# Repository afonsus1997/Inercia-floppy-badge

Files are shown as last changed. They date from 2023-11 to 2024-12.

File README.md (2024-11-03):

# Inércia 2024 Floppy Badge

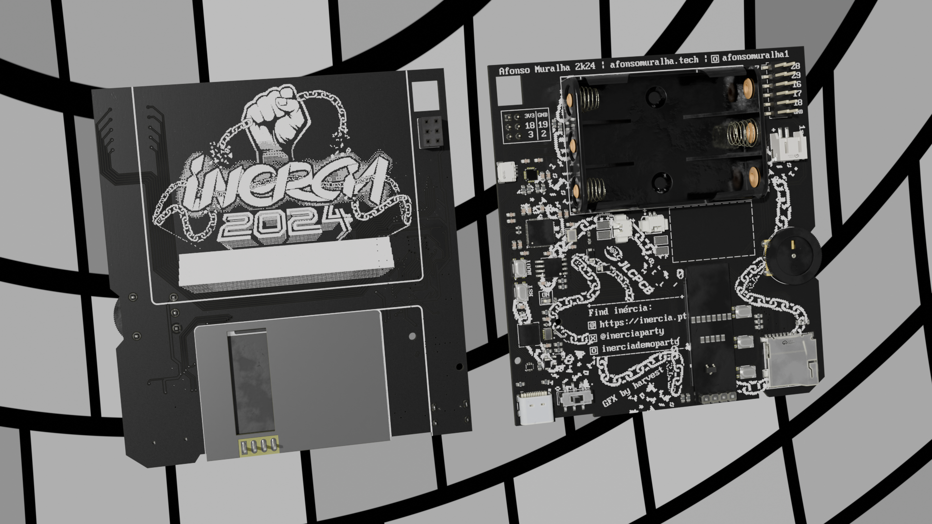
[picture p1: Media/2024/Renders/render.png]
Render


## Introduction

Missed last year’s Inércia 2023 badge? This year, they’re back and even better! Inércia 2024 badges now come with a mini OLED screen—perfect for displaying custom text, animations, and more, alongside the ability to play your favorite .mod tunes. 

## Sponsors

JLCPCB LOGO

JLCPCB helped make this project possible! All the manufacturing and assembly of the prototypes and the final badges were made using JLCPCB services.

[Check out JLCPCB here!](https://jlcpcb.com/)

## Specifications and Features

- **Processor:** RP2040
- **Memory:** 264kB on-chip SRAM, 32Mb external flash
- **Power Supply:** USB or 3xAAA
- **Connectivity:** USB, external GPIO, SAO
- **Dimensions:** Very close to a real floppy!
## Design Files and Schematics

All design files, including schematics, PCB layouts, and 3D models, are available for download:

- [Kicad Project folder](Hardware/2024/mod-badge-inercia)
- [Schematic PDF](Hardware/2024/mod-badge-inercia/mod-badge-inercia.pdf)
- [3D Models (STEP)](Hardware/2024/mod-badge-inercia/mod-badge-inercia.step)

## Pictures and Renders

Below are some pictures and renders of the project to give you a closer look:

- Top View
- Side View
- 3D Render

## Changelog

### Credits

- oled footprint from: https://github.com/gorbachev/KiCad-SSD1306-0.91-OLED-4pin-128x32.pretty
- oled 3d model from Stilet Fox (https://grabcad.com/library/oled-0-91-128x32-1)
- battery holder 3d model from Tomasz (https://grabcad.com/library/3-x-aaa-battery-holder)
- potentiometer model from NGOUBO OLIVIER (https://grabcad.com/library/potentiometer-52)
- push button model from Shawn Melanson (https://grabcad.com/library/skrpace010-push-button-switch-1)
- picoblade model from Владимир «AVRASM1234» Иванишин (https://grabcad.com/library/molex-picoblade-connectors-1-25-mm-right-angle-1)

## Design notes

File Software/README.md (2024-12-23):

# Software Guide

This README provides instructions on setting up the development environment, programming, and debugging the **Inercia Floppy Badge**.

------

## Projects:

- [inercia_badge_sw_pio](https://github.com/afonsus1997/Inercia-floppy-badge/tree/main/Software/inercia_badge_sw_pio) is the main production firmware
- [inercia_badge_sw_tinygl](https://github.com/afonsus1997/Inercia-floppy-badge/tree/main/Software/inercia_badge_sw_tinygl) is the beta version with ported tinyGL lib

## Updating Your Badge

1. Download the latest .uf2 firmware file from the [releases page](https://github.com/afonsus1997/Inercia-floppy-badge/releases).
2. Connect the badge to your PC.
3. With your badge turned off hold the boot button and with the boot button still pressed, turn on the badge. A mass storage device should appear.
4. Copy the .uf2 firmware file to the badge mass storage device.
5. The badge is now updated and should reboot automatically! 

## Development Environment

The development environment is built around [PlatformIO](https://platformio.org), which allows for efficient dependency management and provides greater control over the build process compared to the Arduino IDE. Is it perfect? No. But PlatformIO offers (what seems to us) the best balance of usability, distribution ease, and customization. If you have suggestions for improvement, we’re always open to feedback!

### Setting Up PlatformIO

To get started, install PlatformIO following the official [installation guide](https://platformio.org/install/). You can use:

- **PlatformIO VS Code Extension** for a graphical interface.

- **PlatformIO CLI** for command-line workflows.

> ##### Note: Additional steps when using Windows
> Windows has a default limitation on file path lengths (260 characters), which **WILL** cause issues when working with the PlatformIO project. To avoid errors:
>
> - Enable long file path support in Windows:
>
>   - Open the **Local Group Policy Editor** (`gpedit.msc`).
>
>   - Navigate to `Computer Configuration > Administrative Templates > System > Filesystem`.
>
>   - Enable the policy **Enable Win32 long paths**.
>
>   - Reboot

------

## Accessing the Codebase

The main firmware is located in the [`Software/inercia_badge_sw_pio`](https://github.com/afonsus1997/Inercia-floppy-badge/tree/main/Software/inercia_badge_sw_pio) directory of the repository. This is the most up-to-date source code for the badge.

To begin:

1. Open the project in PlatformIO.
2. Allow PlatformIO to scan the project files.

------

## Build Environments

Once the project is loaded, you’ll find two build environments in the `platformio.ini` file:

1. **`env:pico_usb`**
   - Use this for flashing the badge firmware via USB.
2. **`env:pico_cmsis`**
   - Select this if you are using a debug probe. [More info here](#).

> ##### Note: (more) Additional steps when using Windows
> For the first **USB** firmware upload, you need to plug in the badge with the BOOTL button pressed so that it shows up as UF2 drive.
> Then, use Zadig to change the driver of the RP2040 to WinUSB.

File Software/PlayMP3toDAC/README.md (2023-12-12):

# Inércia 2023 Floppy Badge MP3 Support

This little *CircuitPython* script allows for the playback of .mp3 (and .wav if you really want to) from local storage and micro SD card.

## Usage

Flash CircuitPython 8.x from [here](https://circuitpython.org/board/raspberry_pi_pico/) onto the badge.

After the reboot copy the `lib` directory and `code.py` to the root of the, now available, `CIRCUITPY` device/directory on your computer.

The mixer in the firmware expects a single channel with a sample rate of 22050 Hz, so there is a `resampler.py` script that expects mp3 files in a mp3 folder and resamples everything to the required format. There's also a `requirements.txt` file. I recommend you use `venv` or something of the sorts.

Place your mp3 files into an `mp3` directory on you micro SD card.

That's pretty much it. Power the badge and it should play sound.

## Dependencies

- CircuitPython 8.x
- Adafruit CircuitPython Bundle 8.x

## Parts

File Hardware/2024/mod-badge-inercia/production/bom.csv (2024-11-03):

Designator | Footprint | Quantity | Value | LCSC Part #
C10, C11, C12, C14, C17, C19, C3, C4, C6, C7, C8, C9 | 0603 | 12 | 100n | C478888
C13, C5 | 0603 | 2 | 1u | C302042
C15, C16 | 0603 | 2 | 27p | C107045
C18, C22 | 0603 | 2 | 10u | C95839
C20, C21 | 0603 | 2 | 220p | C5255295
C23 | 0603 | 1 | 22u | C59461
D1, D101, D102 | D_SOD-123F | 3 | D_Schottky | C50553
D2 | 0603 | 1 | LED | C434424
J1 | USB_C_Receptacle_HCTL_HC-TYPE-C-16P-01A | 1 | USB_C_Receptacle_USB2.0 | C2894897
J101, J4 | CONN-SMD_2P-P1.25_HC_HCZZ0001-2 | 2 | Conn_01x02_Shielded | C7433453
J102 | CONN-SMD_P2.00_S2B-PH-SM4-TB-LF-SN | 1 | Conn_01x02_Shielded | C295747
J2 | J_sd_micro_socket | 1 | Micro_SD_Card_Det1 | C7529389
J3 | JST_SH_SM03B-SRSS-TB_1x03-1MP_P1.00mm_Horizontal | 1 | Conn_01x03_MountingPin | C160403
J6 | OLED_SSD1306_128x32_0.91 | 1 | Conn_01x04
J7 | PinHeader_2x06_P2.54mm_Vertical_SMD | 1 | Conn_02x06_Odd_Even | C3294464
L101 | L_Chilisin_BMRB00050512 | 1 | 0.47uH | C329374
Q1 | SOT-23 | 1 | DMG3415U | C96616
R1 | 0603 | 1 | 511k | C2684557
R10, R13, R14, R17, R18, R20, R9 | 0402 | 7 | 1k | C11702
R103, R24, R3 | 0603 | 3 | 0 | C95177
R105, R108, R2 | 0402 | 3 | 91k | C852952
R106, R107 | 0402 | 2 | 62k | C37825
R109, R110, R111, R5 | 0603 | 4 | 10k | C103199
R11, R12 | 0402 | 2 | 27.4 | C274349
R15, R16 | 0603 | 2 | 4.7k | C99782
R21 | 0603 | 1 | 1M | C3016422
R25, R4 | 0402 | 2 | 100 | C25076
R6, R7 | 0603 | 2 | 5.1k | C407575
SW2, SW3, SW4, SW5, SW6 | SW_SKRPACE010 | 5 | SW_MEC_5E | C139797
SW7 | SS-3235S-L2 | 1 | SW_Push_DPDT | C500056
TP5 | TestPoint_Pad_D1.0mm | 1 | TestPoint
U1 | QFN-56-1EP_7x7mm_P0.4mm_EP3.2x3.2mm | 1 | RP2040 | C2040
U2 | SOT-666 | 1 | USBLC6-2P6 | C2827693
U4 | SOIC-8_5.23x5.23mm_P1.27mm | 1 | W25Q32JVSS | C82344
U5 | QFN50P300X300X80-17N | 1 | MAX98357AETE_T | C910544
U6 | VREG_TPS63802DLAR | 1 | TPS63802DLAR | C2845237
Y1 | Crystal_SMD_3225-4Pin_3.2x2.5mm | 1 | 12MHZ | C5182760

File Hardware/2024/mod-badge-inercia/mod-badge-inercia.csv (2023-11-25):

Source: | C:\Users\afons\Documents\kicad-ws\mod-player\mod-player.kicad_sch
Date: | 10/15/2023 2:59:10 PM
Tool: | Eeschema 7.0.7
Generator: | C:\Program Files\KiCad\7.0\bin\scripting\plugins/bom_csv_grouped_by_value_with_fp.py
Component Count: | 119
Ref | Qnty | Value | Cmp name | Footprint | Description | Vendor | DNP
BT1 | 1 | Battery | Battery | mod:AAA-HOLDER-THD | Multiple-cell battery
C1, C2, C22 | 3 | 28uF | C_Small | Capacitor_SMD:C_0603_1608Metric | Unpolarized capacitor, small symbol
C3, C4, C6, C7, C8, C9, C10, C11, C12, C14, C17, C19 | 12 | 100n | C_Small | Capacitor_SMD:C_0603_1608Metric | Unpolarized capacitor, small symbol
C5, C13 | 2 | 1u | C_Small | Capacitor_SMD:C_0603_1608Metric | Unpolarized capacitor, small symbol
C15, C16 | 2 | 27p | C_Small | Capacitor_SMD:C_0603_1608Metric | Unpolarized capacitor, small symbol
C18 | 1 | 10u | C_Small | Capacitor_SMD:C_0603_1608Metric | Unpolarized capacitor, small symbol
C20, C21 | 2 | 220p | C_Small | Capacitor_SMD:C_0603_1608Metric | Unpolarized capacitor, small symbol
D1, D2, D3, D14 | 4 | D_Schottky | D_Schottky | Diode_SMD:D_SOD-123 | Schottky diode
D4, D5, D6, D7, D8, D9, D10, D11, D12, D13 | 10 | LED_ABGR | LED_ABGR | LED_SMD:LED_RGB_Everlight_EASV3015RGBA0_Horizontal | RGB LED, anode/blue/green/red
J1 | 1 | USB_C_Receptacle_USB2.0 | USB_C_Receptacle_USB2.0 | Connector_USB:USB_C_Receptacle_HCTL_HC-TYPE-C-16P-01A | USB 2.0-only Type-C Receptacle connector
J2 | 1 | Micro_SD_Card_Det1 | Micro_SD_Card_Det1 | mod:J_sd_micro_socket | Micro SD Card Socket with one card detection pin
J3 | 1 | Conn_01x03_MountingPin | Conn_01x03_MountingPin | Connector_JST:JST_SH_BM03B-SRSS-TB_1x03-1MP_P1.00mm_Vertical | Generic connectable mounting pin connector, single row, 01x03, script generated (kicad-library-utils/schlib/autogen/connector/)
J4, J5 | 2 | Conn_01x01_Pin | Conn_01x01_Pin | TestPoint:TestPoint_Keystone_5019_Minature | Generic connector, single row, 01x01, script generated
L1, L2 | 2 | 22uH | L | Inductor_SMD:L_Changjiang_FNR5040S | Inductor
Q1, Q2 | 2 | AO3401A | AO3401A | Package_TO_SOT_SMD:SOT-23 | -4.0A Id, -30V Vds, P-Channel MOSFET, SOT-23
Q3 | 1 | NMOS | NMOS | Package_TO_SOT_SMD:SOT-23 | N-MOSFET transistor, drain/source/gate
R1, R30 | 2 | 11.5k | R | Resistor_SMD:R_0603_1608Metric | Resistor
R2, R31 | 2 | 2.55k | R | Resistor_SMD:R_0603_1608Metric | Resistor
R3, R4, R28, R29 | 4 | R | R | Resistor_SMD:R_0603_1608Metric | Resistor
R5, R41, R47 | 3 | 10k | R | Resistor_SMD:R_0603_1608Metric | Resistor
R6, R7 | 2 | 5.1k | R | Resistor_SMD:R_0603_1608Metric | Resistor
R8, R13, R14 | 3 | DNI | R | Resistor_SMD:R_0603_1608Metric | Resistor
R9, R15, R16, R17 | 4 | 1k | R | Resistor_SMD:R_0603_1608Metric | Resistor
R10 | 1 | 1k | R | Resistor_SMD:R_0402_1005Metric | Resistor
R11, R12 | 2 | 27.4 | R | Resistor_SMD:R_0402_1005Metric | Resistor
R19, R22, R23, R24, R32, R33, R34, R35, R36, R48, R49, R50, R52, R53 | 14 | 0 | R | Resistor_SMD:R_0603_1608Metric | Resistor
R21 | 1 | 1M | R | Resistor_SMD:R_0603_1608Metric | Resistor
R25, R26, R37, R38, R39, R40, R42, R43, R44, R45 | 10 | 33 | R | Resistor_SMD:R_0603_1608Metric | Resistor
RV1 | 1 | R_Potentiometer | R_Potentiometer | mod:gear-dial-pot-3pin | Potentiometer
SW2, SW3, SW4, SW5, SW6 | 5 | SW_MEC_5E | SW_MEC_5E | mod:SW_SKRPACE010 | MEC 5E single pole normally-open tactile switch
SW7 | 1 | SW_Push_DPDT | SW_Push_DPDT | Button_Switch_SMD:SW_DPDT_CK_JS202011JCQN | Momentary Switch, dual pole double throw
U1 | 1 | RP2040 | RP2040 | Package_DFN_QFN:QFN-56-1EP_7x7mm_P0.4mm_EP3.2x3.2mm | A microcontroller by Raspberry Pi
U2, U7 | 2 | MT3608 | MT3608 | Package_TO_SOT_SMD:SOT-23-6 | High Efficiency 1.2MHz 2A Step Up Converter, 2-24V Vin, 28V Vout, 4A current limit, 1.2MHz, SOT23-6
U3 | 1 | AMS1117-3.3 | AMS1117-3.3 | Package_TO_SOT_SMD:SOT-223-3_TabPin2 | 1A Low Dropout regulator, positive, 3.3V fixed output, SOT-223
U4 | 1 | W25Q32JVSS | W25Q32JVSS | Package_SO:SOIC-8_5.23x5.23mm_P1.27mm | 32Mb Serial Flash Memory, Standard/Dual/Quad SPI, SOIC-8
U5 | 1 | MAX98357AETE_T | MAX98357AETE_T | mod:QFN50P300X300X80-17N
U6, U8, U9, U10, U11, U12, U13, U14, U15, U16 | 10 | WS2811 | WS2811 | Package_TO_SOT_SMD:SOT-23-8 | 3-Channel 8-Bit PWM LED Driver, DIP-8/SOIC-8
Y1 | 1 | 12MHZ | Crystal_GND24_Small | Crystal:Crystal_SMD_3225-4Pin_3.2x2.5mm | Four pin crystal, GND on pins 2 and 4, small symbol

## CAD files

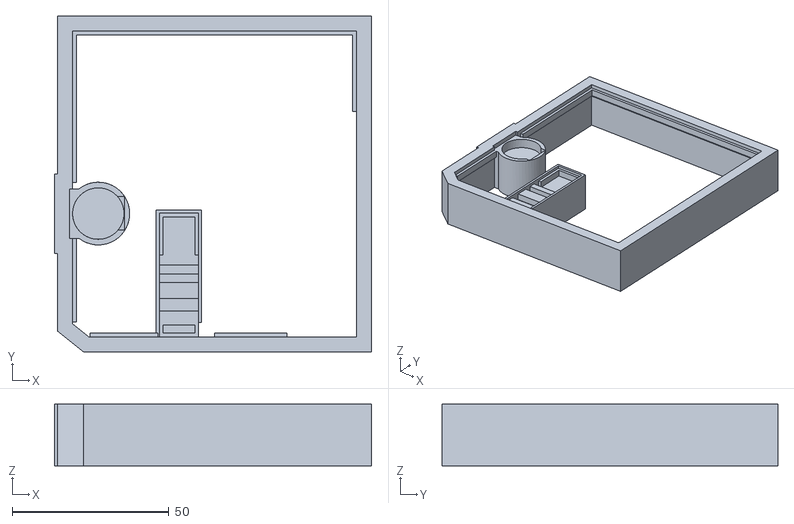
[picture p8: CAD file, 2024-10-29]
Hardware/2024/mod-badge-inercia/floppy_jig.stl
101.0 x 107.0 x 19.6

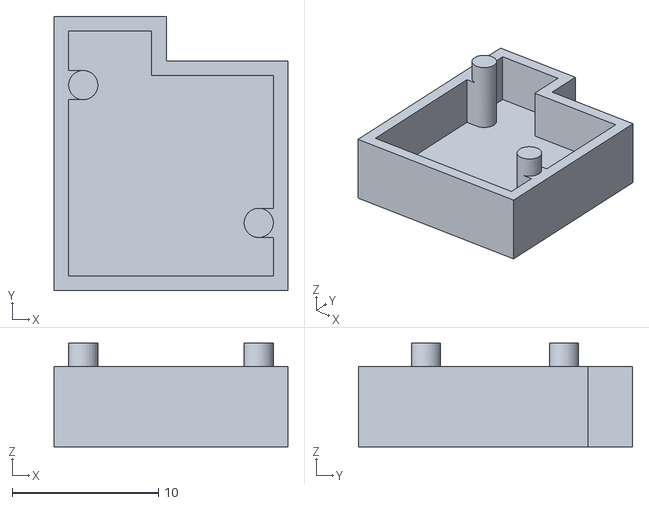
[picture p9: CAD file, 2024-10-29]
Hardware/2024/mod-badge-inercia/Shield.stl
16.0 x 18.8 x 7.10

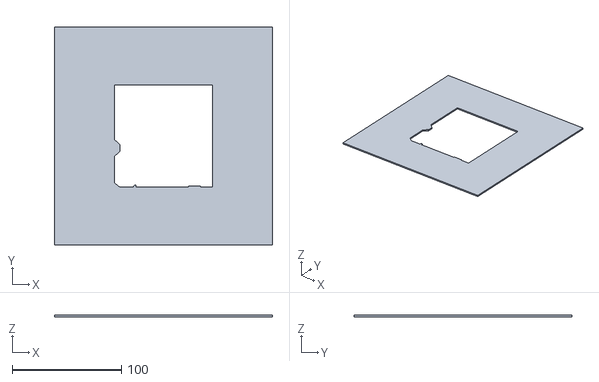
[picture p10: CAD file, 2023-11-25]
Hardware/2024/mod-badge-inercia/stencil_0.stl
200.0 x 200.0 x 1.60

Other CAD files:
Hardware/2024/mod-badge-inercia/stencil_0.2.stl

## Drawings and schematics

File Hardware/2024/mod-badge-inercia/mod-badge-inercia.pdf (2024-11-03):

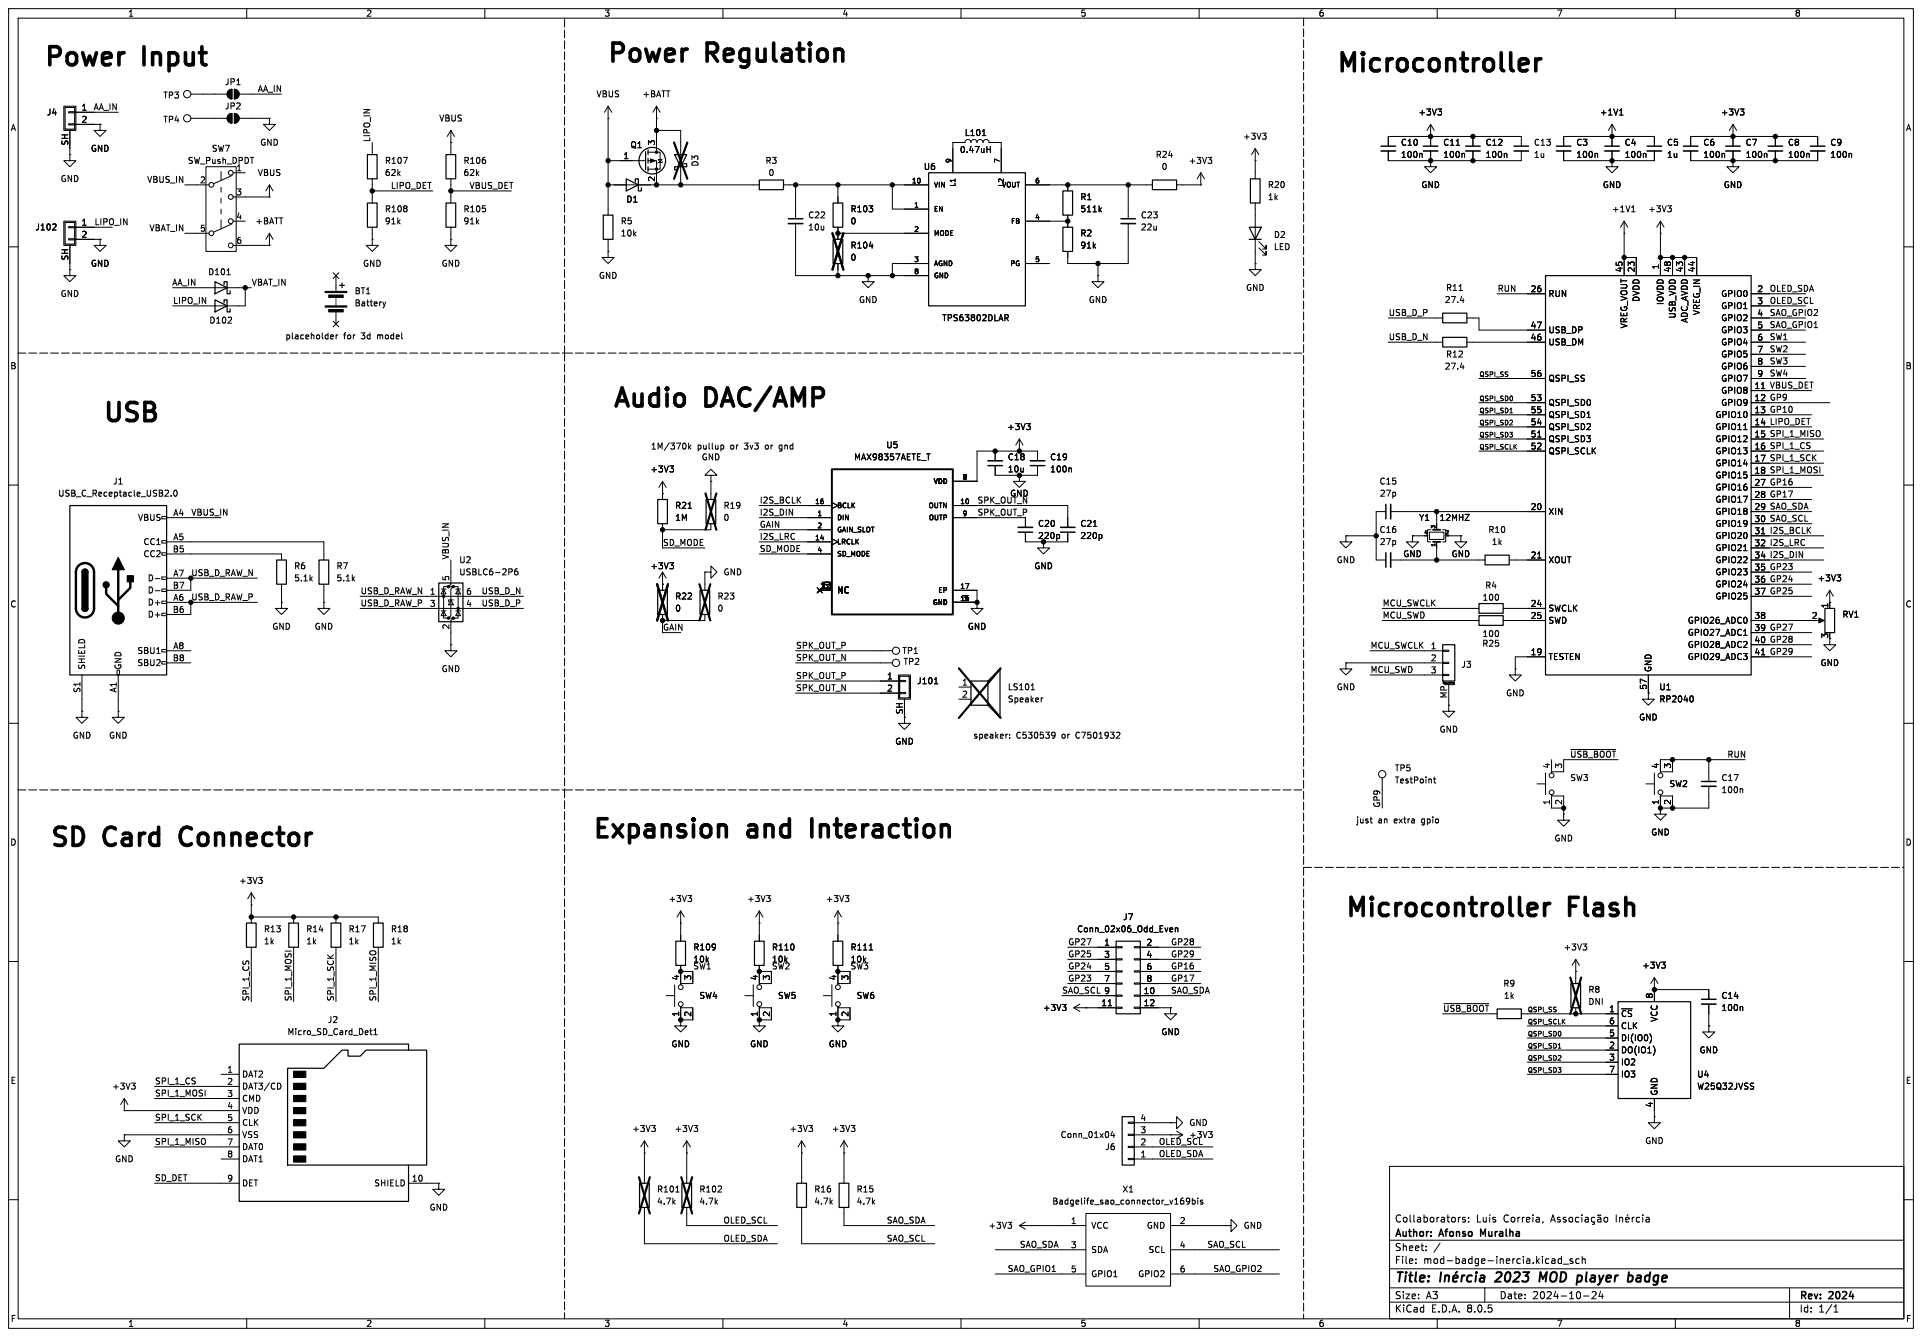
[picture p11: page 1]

just an extra gpio

Id: 1/1 Title: þÿInércia 2023 MOD player badge

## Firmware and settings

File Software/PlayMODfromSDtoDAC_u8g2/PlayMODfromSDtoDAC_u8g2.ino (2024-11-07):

#include <Arduino.h>
#include <SPI.h>
#include <Wire.h>
#include <U8g2lib.h>  // Include the U8g2 library
#include "inercia_bitmap.h"
#include "AudioGeneratorMOD.h"
#include "AudioOutputI2S.h"
#include "AudioFileSourceSD.h"
#include <pico/multicore.h>

// u8g2 fonts
// https://raw.githubusercontent.com/olikraus/u8g2/master/doc/u8g2fntlistall.pdf


// OLED Display Configuration
#define MINSWING 1
#define MAXSWING 64

// Audio and Button Configuration
#define TOP_BUTTON 5
#define MID_BUTTON 6
#define BOT_BUTTON 4
#define POT_PIN A0

bool fileChanged = false;  // Flag to signal file change
int fileIndex = 0;
float volume = 0.1;
float previousVolume = 0.1;
bool isLoading = false;

// Variables for Animation
int rotation;
uint8_t swing;
uint8_t counter;
uint8_t once_every;
bool swing_direction;

// Display Setup
U8G2_SSD1306_128X32_UNIVISION_F_HW_I2C u8g2(U8G2_R0);  // U8g2 display setup

// Audio Setup
AudioGeneratorMOD *mod;
AudioFileSourceSD *fileO;
AudioOutputI2S *out;
uint16_t fileCount = 0;

// Button states and debounce
struct Button {
  int pin;
  int state;
  int lastState = HIGH;
  unsigned long lastDebounceTime = 0;
  bool activated = false;
};

Button topButton = { TOP_BUTTON, HIGH };
Button midButton = { MID_BUTTON, HIGH };
Button botButton = { BOT_BUTTON, HIGH };
unsigned long debounceDelay = 50;

// Shared variables for now playing message
char nowPlaying[30];                // Buffer for the currently playing file name
bool displayingNowPlaying = false;  // Flag to control now playing visibility
unsigned long displayTime = 0;      // Time when the now playing message was displayed

// Shared variables for volume popup
bool displayingVolumePopup = false; // Single flag for volume popup
unsigned long volumePopupTime = 0;  // Timer for the popup duration

// Function Prototypes
void core1_displayTask();
void readButtons();
void checkButton(Button &button);
void handleButtonActions();
void resetButtonActivations();
void playFile(int index);
void drawRotatedBitmap(uint8_t x, uint8_t y, const uint8_t *bitmap, uint8_t width, uint8_t height, int angle);
void core0_audioTask();
void drawVolumePopup(int volume);
void drawNowPlaying(const String& nowPlaying);

void setup() {
  Serial.begin(115200);
  delay(1000);
  // Initialize button pins
  pinMode(topButton.pin, INPUT);
  pinMode(midButton.pin, INPUT);
  pinMode(botButton.pin, INPUT);
  pinMode(POT_PIN, INPUT);

  // Start core1 for display handling
  multicore_launch_core1(core1_displayTask);

  // Start audio handling on the main core
  out = new AudioOutputI2S(22000, 20, 22);
  out->SetGain(volume);
  mod = new AudioGeneratorMOD();
  mod->SetBufferSize(1024);
  mod->SetSampleRate(22000);
  mod->SetStereoSeparation(64);

  // Initialize SD card and count MOD files
  if (!SD.begin(13, 1000000UL * 1000, SPI1)) {
    Serial.println("SD initialization failed!");
    while (1);
  }
  Serial.println("SD initialized successfully.");

  File root = SD.open("/");
  if (!root) {
    Serial.println("Failed to open directory.");
    return;  // Exit if the directory cannot be opened
  }

  // List all MOD files found
  Serial.println("Available MOD files:");
  while (File entry = root.openNextFile()) {
    if (!entry.isDirectory() && strstr(entry.name(), ".mod")) {
      Serial.printf("Index %d: %s\n", fileCount, entry.name());
      fileCount++;
    }
    entry.close();
  }

  if (fileCount == 0) {
    Serial.println("No MOD files found.");
    return;  // Exit if no files were found
  }

  Serial.print("MODs found: ");
  Serial.println(fileCount);

  // Seed and play initial file
  randomSeed(analogRead(A1));
  fileIndex = random(0, fileCount);
  playFile(fileIndex);
  Serial.println("Playing file...");
  isLoading = true;
}

// Main loop function
void loop() {
  if (!isLoading) {
    readButtons();
  }

  // Adjust volume
  float newVolume = map(analogRead(POT_PIN), 4, 1023, 0, 100) / 100.0;

  // Check if volume change exceeds 2%
  if (abs(newVolume - previousVolume) > 0.03) {
      displayingVolumePopup = true; // Show the volume popup
      volumePopupTime = millis();   // Reset the timer for popup
      previousVolume = newVolume;    // Update the previous volume
  }
  
  // Update the audio output gain
  out->SetGain(newVolume);

  // Hide the volume popup after 1 second
  if (displayingVolumePopup && (millis() - volumePopupTime >= 1000)) {
      displayingVolumePopup = false; // Hide the popup after 1 second
  }

  if (mod->isRunning()) {
    if (!mod->loop()) {
      Serial.println("Audio loop finished.");
      mod->stop();
    }
    isLoading = false;
    handleButtonActions();
  } else if (!isLoading && !midButton.activated) {
    Serial.println("MOD done");
    fileIndex = (fileIndex + 1) % fileCount;  // Play the next file in the list
    playFile(fileIndex);
  }

  resetButtonActivations();  // Reset button states after processing
}

void core1_displayTask() {
    // Initialize display
    Wire.setSDA(0);
    Wire.setSCL(1);
    u8g2.begin(); // Initialize U8g2

    // Initialize animation variables
    counter = 0;
    once_every = 4;
    rotation = 0;
    swing = MINSWING;
    swing_direction = true;

    while (true) {
        // Animation logic
        u8g2.clearBuffer();
        drawRotatedBitmap(swing, swing / 3, inercia_bmp, INERCIA_W, INERCIA_H, rotation);

        // Safely read nowPlaying using critical section
        noInterrupts();
        u8g2.setFont(u8g2_font_5x8_tr); // Set a font that is 8px tall
        u8g2.setDrawColor(1); // Set color to white
        
        if (displayingNowPlaying) {
            drawNowPlaying(nowPlaying);
        }

        // Draw volume popup if necessary
        if (displayingVolumePopup) {
            drawVolumePopup((int)(previousVolume * 100)); // Convert previous volume to percentage
        }
        
        interrupts();

        // Send buffer to display
        u8g2.sendBuffer();
        
        rotation = (rotation + 1) % 360; // Increment the rotation angle
        if (++counter >= once_every) {
            counter = 0;
            swing += (swing_direction ? 1 : -1);
            if (swing >= MAXSWING || swing <= MINSWING) swing_direction = !swing_direction;
        }

        // Check if we need to hide the now playing message
        if (displayingNowPlaying && (millis() - displayTime >= 3000)) {
            displayingNowPlaying = false; // Hide the now playing message
        }

        // Add a short delay to prevent busy-waiting
        delay(10);
    }
}

void readButtons() {
  checkButton(topButton);
  checkButton(midButton);
  checkButton(botButton);
}

void checkButton(Button &button) {
  int reading = digitalRead(button.pin);

  if (reading != button.lastState) {
    button.lastDebounceTime = millis();
  }

  if ((millis() - button.lastDebounceTime) > debounceDelay && reading != button.state) {
    button.state = reading;
    if (button.state == LOW) {
      button.activated = true;
      Serial.printf("%s Button pressed!\n", button.pin == TOP_BUTTON ? "Top" : button.pin == MID_BUTTON ? "Mid" : "Bot");
    }
  }
  button.lastState = reading;
}

void handleButtonActions() {
  if (topButton.activated || botButton.activated) {
    mod->stop();
    if (topButton.activated) {
      // Change to the next file, looping back to the start
      fileIndex = (fileIndex + 1) % fileCount;
      Serial.printf("Next file: %d\n", fileIndex);
    } else if (botButton.activated) {
      // Change to a random file
      fileIndex = random(0, fileCount);
      Serial.printf("Random file: %d\n", fileIndex);
    }
    playFile(fileIndex);  // Play the selected file
    isLoading = true;     // Set loading flag
  }
  if (midButton.activated) {
    // Handle mid button action
    displayingNowPlaying = true; // Show now playing message
    displayTime = millis(); // Reset display time
    strcpy(nowPlaying, "Sample File Name"); // Update with the actual file name
  }
  
}

void resetButtonActivations() {
  topButton.activated = false;
  midButton.activated = false;
  botButton.activated = false;
}

void playFile(int index) {
  File root = SD.open("/mods");
  root.rewindDirectory();

  while (File entry = root.openNextFile()) {
    if (index <= 0 && strstr(entry.name(), ".mod")) {
      Serial.print("Playing: ");
      Serial.println(entry.name());

      // Safely update nowPlaying using critical section
      noInterrupts();
      strncpy(nowPlaying, entry.name(), sizeof(nowPlaying) - 1);
      nowPlaying[sizeof(nowPlaying) - 1] = '\0';  // Ensure null termination

      // Show now playing message
      displayingNowPlaying = true;  // Set flag to show the now playing message
      displayTime = millis();       // Store the current time for display duration

      interrupts();

      fileO = new AudioFileSourceSD(entry.name());
      mod->begin(fileO, out);
      entry.close();
      break;
    }
    entry.close();
    index--;
  }
}

void drawRotatedBitmap(uint8_t x, uint8_t y, const uint8_t *bitmap, uint8_t width, uint8_t height, int angle) {
  int8_t old_x, old_y, new_x, new_y;
  uint8_t pivot_x = width / 2;
  uint8_t pivot_y = height / 2;
  float angle_rad = angle / 57.3;  // Convert to radians
  float sin_angle = sin(angle_rad);
  float cos_angle = cos(angle_rad);

  for (int row = 0; row < height; row++) {
    uint8_t displayData, mask = 0;
    for (int col = 0; col < width; col++) {
      if (mask == 0) {
        displayData = pgm_read_byte(bitmap++);
        mask = 0x80;
      }
      if (displayData & mask) {
        old_x = col - pivot_x;
        old_y = row - pivot_y;
        new_x = (int)(old_x * cos_angle - old_y * sin_angle) + pivot_x + x;
        new_y = (int)(old_x * sin_angle + old_y * cos_angle) + pivot_y + y;
        u8g2.drawPixel(new_x, new_y);  // Use U8g2 to draw the pixel
      }
      mask >>= 1;
    }
  }
}


void drawVolumePopup(int volume) {
    // Prepare text for display
    String volumeText = "Vol: " + String(volume) + "%";

    // Calculate text width and height
    int textWidth = u8g2.getStrWidth(volumeText.c_str());
    int textHeight = u8g2.getFontAscent() - u8g2.getFontDescent(); // Height of the text box

    // Calculate dimensions and position for the popup box
    int padding = 4; // Padding around the text
    int boxWidth = textWidth + 2 * padding; // Box width based on text width and padding
    int boxHeight = textHeight + 2 * padding; // Box height based on text height and padding
    int x = (128 - boxWidth) / 2; // Center the box horizontally
    int y = (32 - boxHeight) / 2; // Center the box vertically

    // Draw the outline (white)
    u8g2.setDrawColor(1); // Set color to white for outline
    u8g2.drawFrame(x, y, boxWidth, boxHeight); // Draw the outline frame

    // Fill the box (black)
    u8g2.setDrawColor(0); // Set color to black for filling
    u8g2.drawBox(x + 1, y + 1, boxWidth - 2, boxHeight - 2); // Draw filled box with padding for outline

    // Set text properties
    u8g2.setDrawColor(1); // Set color to white for text
    u8g2.setFont(u8g2_font_5x8_tr); // Set font for popup
    u8g2.setCursor(x + padding, y + padding + textHeight - u8g2.getFontDescent()); // Position the text inside the box, adjusted for descent
    u8g2.print(volumeText); // Display the volume text
}

int scrollOffset = 0; // Offset for scrolling text
int scrollSpeed = 1;  // Speed of scrolling

void drawNowPlaying(const String& nowPlaying) {
    // Prepare text for display
    String nowPlayingText = "Now Playing:";
    
    // Set the maximum box width based on the screen size
    const int maxBoxWidth = 128;

    // Define padding
    int padding = 4; // Padding around the text

    // Calculate text height
    int textHeight = u8g2.getFontAscent() - u8g2.getFontDescent(); // Height of the text

    // Calculate the width for the music glyph
    int musicGlyphWidth = 10; // Adjust this value based on your glyph size

    // Calculate the width for the title text
    int titleTextWidth = u8g2.getStrWidth(nowPlayingText.c_str());

    // Start with the full nowPlaying text
    String truncatedNowPlaying = nowPlaying;
    int fileNameWidth = u8g2.getStrWidth(truncatedNowPlaying.c_str());
    
    // Calculate total width required for title and glyph
    int totalWidth = titleTextWidth + musicGlyphWidth + 2 * padding; // Title + glyph + padding
    
    // Calculate box width and ensure it doesn't exceed the max width
    int boxWidth = max(totalWidth, fileNameWidth + 2 * padding); // Box width based on text widths
    if (boxWidth > maxBoxWidth) boxWidth = maxBoxWidth; // Ensure box width does not exceed screen width

    // Adjust the box width based on the title and glyph size
    int availableWidth = boxWidth - totalWidth;
    fileNameWidth = availableWidth;

    // Truncate the nowPlaying text if it exceeds the available width
    while (fileNameWidth > availableWidth && truncatedNowPlaying.length() > 0) {
        truncatedNowPlaying.remove(truncatedNowPlaying.length() - 1); // Remove last character
    }

    // Calculate the final box height and position
    int boxHeight = textHeight * 2 + 3 * padding; // Box height for two lines of text and padding
    int x = (maxBoxWidth - boxWidth) / 2; // Center the box horizontally
    int y = (32 - boxHeight) / 2; // Center the box vertically

    // Draw the outline (white)
    u8g2.setDrawColor(1); // Set color to white for outline
    u8g2.drawFrame(x, y, boxWidth, boxHeight); // Draw the outline frame

    // Fill the box (black)
    u8g2.setDrawColor(0); // Set color to black for filling
    u8g2.drawBox(x + 1, y + 1, boxWidth - 2, boxHeight - 2); // Draw filled box with padding for outline

    // Draw music glyph
    u8g2.setFont(u8g2_font_open_iconic_all_1x_t); // Switch to an icon font
    u8g2.setDrawColor(1); // Set color to white for the glyph
    u8g2.drawGlyph(x + padding, y + padding + textHeight - u8g2.getFontDescent(), 0xE1); // Music icon position

    // Set text properties for the title
    u8g2.setDrawColor(1); // Set color to white for text
    u8g2.setFont(u8g2_font_5x8_tr); // Set font for title
    u8g2.setCursor(x + padding + musicGlyphWidth, y + padding + textHeight - u8g2.getFontDescent()); // Position title text inside the box
    u8g2.print(nowPlayingText); // Display the title text

    // Set text properties for the truncated file name
    u8g2.setCursor(x + padding, y + padding + textHeight + padding + (textHeight - u8g2.getFontDescent())); // Position file name text inside the box
    u8g2.print(truncatedNowPlaying); // Display the truncated current file name
}

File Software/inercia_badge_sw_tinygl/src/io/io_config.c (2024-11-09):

#include "io_config.h"
#include <Arduino.h>

/* I2C0 Config */
 const uint8_t kIoPinI2c0Sda = 0;
 const uint8_t kIoPinI2c0Scl = 1;

/* I2C1 Config */
 const uint8_t kIoPinI2c1Sda = 18;
 const uint8_t kIoPinI2c1Scl = 19;

/* OLED Config */
 const uint8_t kIoPinOledSda = kIoPinI2c0Sda;
 const uint8_t kIoPinOledScl = kIoPinI2c0Scl;

/* Potentiometer*/
 const uint8_t kIoPotPin = A0;

/* Buttons */
 const uint8_t kIoButtonTopPin = 5;
 const uint8_t kIoButtonMidPin = 6;
 const uint8_t kIoButtonBotPin = 4;

/* RNG Pin*/
 const uint8_t kIoRngPin = A1;

/* I2S Pins */
const uint8_t kIoI2sSckPin = 20;
 const uint8_t kIoRI2sDataPin = 22;



 io_pin_config_t io_pin_config[kIoPinAmmountSize] = {
  /* EXP Header */
  {17, INPUT},
  {18, INPUT}, /* ! This is shared with SAO! */
  {19, INPUT}, /* ! This is shared with SAO! */
  {23, INPUT},
  {24, INPUT},
  {25, INPUT},
  {27, INPUT},
  {28, INPUT},
  {29, INPUT},
  /* EXP Header */
  {2, OUTPUT},
  {3, OUTPUT},
  /* Potentiometer */
  {kIoPotPin, INPUT},
  /* Buttons */
  {kIoButtonTopPin, INPUT},
  {kIoButtonMidPin, INPUT},
  {kIoButtonBotPin, INPUT}
};


 io_button_t io_buttons[kIoButtonAmmount] = {
  {kIoButtonTopPin, HIGH, HIGH, 0, false},
  {kIoButtonMidPin, HIGH, HIGH, 0, false},
  {kIoButtonBotPin, HIGH, HIGH, 0, false}
};

 const uint8_t io_analog_pins[kIoAnalogInAmmount] = { kIoPotPin };


 const unsigned long kIoDebounceDelay = 50;
 const unsigned long KIoVolumeDebounceDelay = 30;
 const float kIoPotDeadZone = 0.03;

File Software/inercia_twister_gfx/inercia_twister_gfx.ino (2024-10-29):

/**
   floppy badge animation for Inercia

   2024 - Luis Correia (luisfcorreia on github)

*/

#include <SPI.h>
#include <Wire.h>
#include <Adafruit_GFX.h>
#include <Adafruit_SSD1306.h>
#include "inercia_bitmap.h"

#define SCREEN_WIDTH 128
#define SCREEN_HEIGHT 32
#define SCREEN_ADDRESS 0x3C
#define MINSWING 1
#define MAXSWING 64

int rotation;
uint8_t swing;
uint8_t counter;
uint8_t once_every;
bool swing_direction;
float scale;

Adafruit_SSD1306 display(SCREEN_WIDTH, SCREEN_HEIGHT, &Wire, -1);

void setup() {
  Serial.begin(9600);

  /**
     We're using this on a Pico with alternative pinout
     setting them up here, before calling display.begin
  */
  Wire.setSDA(0);
  Wire.setSCL(1);

  // SSD1306_SWITCHCAPVCC init
  if (!display.begin(SSD1306_SWITCHCAPVCC, SCREEN_ADDRESS)) {
    Serial.println(F("SSD1306 startup failed"));
    for (;;);
  }
  /**
     set display brightness to dim, for dark environments...
  */
  display.dim(1);

  counter = 0;
  once_every = 4;
  rotation = 0;
  swing = MINSWING;
  swing_direction = true;
}

void loop() {

  display.clearDisplay();
  drawRotatedBitmap(swing, swing / 3, inercia_bmp, INERCIA_W, INERCIA_H, rotation);
  display.display();

  rotation++;
  if (rotation >= 359) rotation = 0;

  counter++;
  if (counter >= once_every) {
    counter = 0;
    // manage direction
    if (swing_direction) {
      swing++;
      if (swing >= MAXSWING) swing_direction = false;
    } else {
      swing--;
      if (swing <= MINSWING) swing_direction = true;
    }
  }
}

void drawRotatedBitmap(uint8_t x, uint8_t y, const uint8_t * bitmap, uint8_t width, uint8_t height, int angle) {
  int8_t old_x, old_y, new_x, new_y;                 // old and new (rotated) Pixel-Coordinates
  uint8_t pivot_x = width / 2;                       // Calculate the (rotation) center of the image (x fraction)
  uint8_t pivot_y = height / 2;                      // Calculate the (rotation) center of the image (y fraction)
  float angle_rad = angle / 57.3;
  float sin_angle = sin(angle_rad);                  // Lookup the sine
  float cos_angle = cos(angle_rad);                  // Lookup the cosine
  for (int row = 0; row < height; row++) {
    uint8_t displayData, mask = 0;
    for (int col = 0; col < width; col++) {
      if (mask == 0) {
        displayData = pgm_read_byte(bitmap++);       // Read the image data from PROGMEM
        mask = 0x80;                                 //MSB first
      }
      if (displayData & mask) {                      // i.e. a pixel
        old_x = col - pivot_x;                       // Calculate the x-position of the Pixel to be rotated
        old_y = row - pivot_y;                       // Calculate the y-position of the Pixel to be rotated
        new_x = (int) (old_x * cos_angle - old_y * sin_angle); // Calculate the x-position of the rotated Pixel
        new_y = (int) (old_y * cos_angle + old_x * sin_angle); // Calculate the y-position of the rotated Pixel
        display.drawPixel(x + pivot_x + new_x, y + pivot_y + new_y, WHITE);
      }
      mask >>= 1;                       //ready for next bit
    }
  }
}

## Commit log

2023-11-29 added volume wheel. code is still a mess
2023-12-05 Minor updates and fixes
    [PlayMODfromSDtoDAC.ino]
2024-09-25 started doing power
    [mod-badge-inercia.kicad_sch]
2024-09-25 added oled and sao connector
    [mod-badge-inercia.kicad_sch]
2024-09-25 minor routing improvements
    [mod-badge-inercia.kicad_pcb, mod-badge-inercia.kicad_sch]
2024-09-25 More routing and schematic improvements
    [mod-badge-inercia.kicad_pcb, mod-badge-inercia.kicad_sch]
2024-09-25 fixed oled orientation
    [mod-badge-inercia.kicad_pcb, mod-badge-inercia.kicad_sch]
2024-09-26 layout improvements
    [mod-badge-inercia.kicad_pcb]
2024-09-26 prototype sent to fab
    [bom.csv, designators.csv, mod-badge-inercia.kicad_pcb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]
2024-10-10 added bom
2024-10-16 added missing connectors, updated speaker, minor changes and improvements
    [bom.csv, designators.csv, mod-badge-inercia.kicad_pcb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]
2024-10-18 Added lipo and usb detection. Updated components and bom consolidation
    [mod-badge-inercia.kicad_pcb, mod-badge-inercia.kicad_sch]
2024-10-18 changed battery holder to 3x
    [mod-badge-inercia.kicad_pcb, mod-badge-inercia.kicad_sch]
2024-10-20 deleted testing circuits, routing improvements
    [mod-badge-inercia.kicad_pcb, mod-badge-inercia.kicad_sch]
2024-10-20 preparing for final pre-production
    [bom.csv, designators.csv, mod-badge-inercia.kicad_pcb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]
2024-10-21 minor schematic and layout improvements
    [mod-badge-inercia.kicad_pcb, mod-badge-inercia.kicad_sch]
2024-10-21 added usb protection
    [bom.csv, designators.csv, mod-badge-inercia.kicad_pcb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]
2024-10-21 Better power management. Added power LED. Misc improvements
    [bom.csv, designators.csv, mod-badge-inercia.kicad_pcb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]
2024-10-21 fixed mos
    [mod-badge-inercia.kicad_pcb, mod-badge-inercia.kicad_sch]
2024-10-21 added back gfx
    [designators.csv, positions.csv]
2024-10-21 added JLCPCB logo
    [designators.csv, positions.csv]
2024-10-21 updated components, sent to fab
    [designators.csv, mod-badge-inercia.kicad_sch, positions.csv]
2024-10-22 updated component
    [bom.csv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]
2024-10-24 Schematic tidy-up, exported schematics
    [mod-badge-inercia.kicad_sch]
2024-10-26 Updated steps, added jig, added some models
    [floppy_jig.stl]
2024-10-28 Added alternative connectors for new battery holder
    [bom.csv, designators.csv, mod-badge-inercia.kicad_sch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]
2024-10-28 minor fix
    [mod-badge-inercia.kicad_sch, positions.csv]
2024-10-29 Minor fixes and updates. Addresses problem with dying dcdc
    [Shield.stl, bom.csv, designators.csv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]
2024-10-29 restructured repo
    [mod-badge-inercia-B_Mask.gbs, mod-badge-inercia-B_Paste.gbp, mod-badge-inercia-B_Silkscreen.gbo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]
2024-10-29 moved project to 2024 folder
    [Shield.stl, bom.csv, designators.csv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]
2024-10-29 minor changes and fixes
    [bom.csv, mod-badge-inercia.kicad_sch, positions.csv]
2024-10-31 adjusted the slot slightly (-0.3, -1)
2024-11-03 Minor changes and bom consolidation
    [bom.csv, designators.csv, mod-badge-inercia.kicad_sch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]
2024-11-03 updated sao connector. minor changes
    [bom.csv, designators.csv, mod-badge-inercia.kicad_sch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]
2024-11-03 minor fixes, sent final 2024 badges to production
    [bom.csv, mod-badge-inercia.kicad_sch]
2024-11-07 started porting and refactoring arduino code
2024-11-07 more button dev
2024-11-07 started implementing player. minor refactoring and fixes
    [PlayMODfromSDtoDAC_u8g2.ino, io.cpp, main.cpp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]
2024-12-23 fix: remove hardcoded value for track number
    [player.cpp]
